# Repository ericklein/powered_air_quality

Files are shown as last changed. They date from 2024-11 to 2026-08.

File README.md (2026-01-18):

# Powered Air Quality
AI: Add hero show with new enclosure :)
## Purpose
Powered Air Quality, aka PAQ, samples, displays, and if connected to WiFi, logs the following air characteristics:
- Temperature (fahrenheit)
- Humidity
- CO2 (carbon dioxide)
- PM2.5 (air particulate)
- VOC (volatile organic compounds) index
- NOx (nitrogen oxide) index (requires SEN6x sensor)

If PAQ is connected to WiFi, it can log this information to a number of network endpoints.

PAQ was created to answer three primary questions:
- Is the co2 level in the room good?
- What is the particulate count in the air outside, and how much of that got into the room? This is particularly relevant during fire season.
- When we use the gas stove or the central heater, how does it change our indoor air quality?

## Associated projects
PAQ has a number of sibling projects that share many common hardware and code attributes. Those are:
- [Air Quality](https://github.com/ericklein/air_quality) has the same functionality as PAQ minus air particulate measurement. It is powered by a battery
- [RCO2](https://github.com/ericklein/rco2) is a small, portable version of Air Quality that only samples and displays air quality levels.
- [Badge](https://github.com/ericklein/badge) is RCO2 in a badge form factor capable of displaying additional information beyond air quality levels.
## Features
NOTE: All screens are engineering art, not final design :)

PAQ exposes air characteristics through a number of screens. When the device is idle, it displays the CO2 ppm level as moving text to protect the screen (eg. screensaver mode)
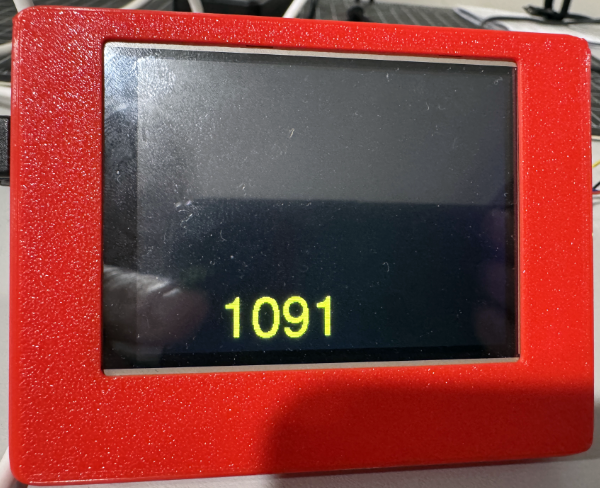
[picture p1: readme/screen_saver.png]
PAQ screensaver picture


If the screen is touched while in screensaver mode, it will display the main menu. Touching any of the options takes the user to the corresponding component information screen.

The main menu varies if the device is configured with a SEN66, which can detect NOx levels
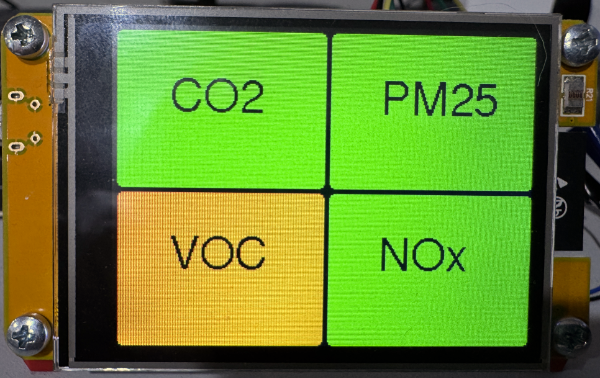
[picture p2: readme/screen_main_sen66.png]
PAQ SEN66 main menu picture


or with the combination of an SCD40 and SEN54, which can not detech NOx levels.
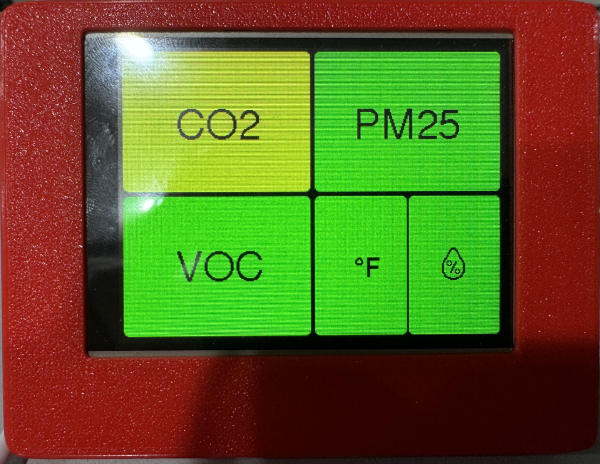
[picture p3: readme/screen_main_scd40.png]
PAQ SCD40 main menu picture


If CO2 is selected from the main menu, it will display a screen highlighting the current CO2 level in ppm and US standard color code level, plus a graph of most recent values. Tapping anywhere on the screen will return to the main menu.
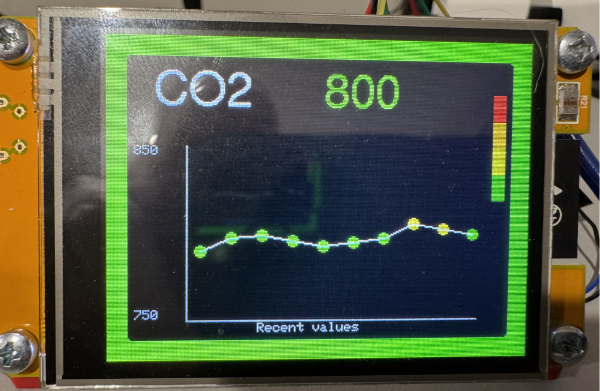
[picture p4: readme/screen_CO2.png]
PAQ co2 screen picture


If VOC is selected from the main menu, it will display a screen highlighting the current VOC level in ppm and US standard color code level, plus a graph of most recent values. Tapping anywhere on the screen will return to the main menu.
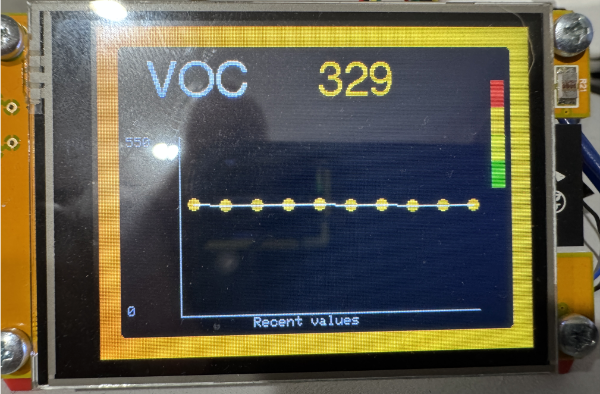
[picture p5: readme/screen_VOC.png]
PAQ VOC screen picture


If PM25 is selected from the main menu, it will display a screen highlighting the current indoor and outdoor PM25 level in ppm and US standard color code level, plus the current outdoor US AQI level. It will also display a red or green database icon if the device is succeeding at logging data to network endpoints. Tapping anywhere on the screen will return to the main menu.
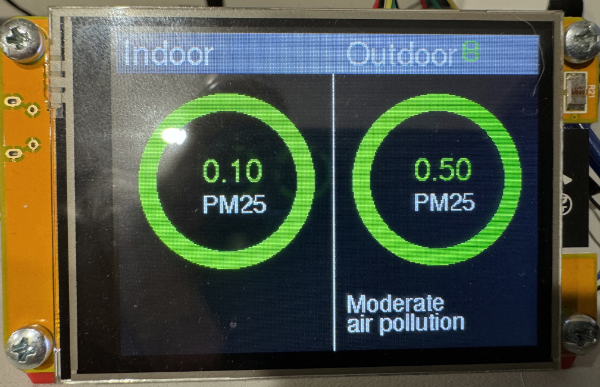
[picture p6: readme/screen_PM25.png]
PAQ PM25 screen picture


If NOx is selected from the main menu, it will display a screen highlighting the current NOx level in ppm and US standard color code level. Tapping anywhere on the screen will return to the main menu.
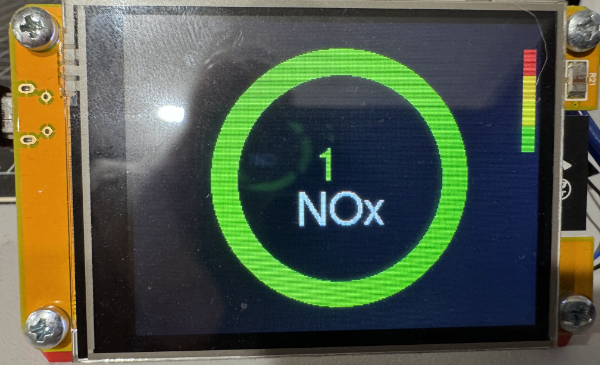
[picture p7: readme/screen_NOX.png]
PAQ SEN66 NOx screen picture


If temp/humidity is selected from the main menu, it will display a screen highlighting the current indoor and outdoor temperature in Fahrenheit and humdidity. It will also display the current WiFi connectivity level in the upper right of the screen. Tapping anywhere on the screen will return to the main menu.
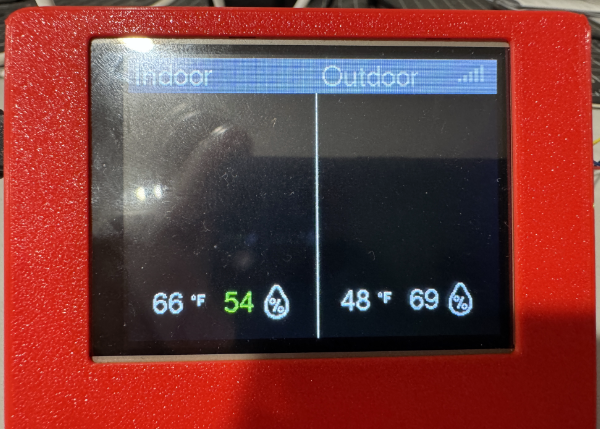
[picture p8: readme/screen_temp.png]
PAQ temp/humidity screen picture

## Target configuration
- Set parameter configuration using config.h
- Private configuration settings including network endpoint credentials are contained in a `secrets.h` file that is not included in this repo.  Instead you'll find the file `secrets_template.h`, which should be copied to `secrets.h` and then edited to supply the right access credentials and configuration values to match your deployment environment.
- Copy the contents of the "put in TFT_eSPI folder" into the "TFT_eSPI" folder found in your Arduino library folder.
- If the device can not connect to a WiFi access point, it will bring up a screen directing you to configure the device via a browser portal window. Entering the configuration data in this portal will then reboot the device and connect to the entered WiFi AP.
## Bill of Materials (BOM)
### MCU
- [CYD (Cheap Yellow Display)])(https://github.com/witnessmenow/ESP32-Cheap-Yellow-Display/tree/main). This is an inexpensive ESP32 prototype board with a built-in screen.
    - Arduino IDE should be told to target the "ESP32 Dev Module" board, which you can find once you install the ESP32 BSP
    - Code is portable to any ESP32 MCU
### WiFi
- [CYD (Cheap Yellow Display)])(https://github.com/witnessmenow/ESP32-Cheap-Yellow-Display/tree/main). This is an inexpensive ESP32 prototype board with a built-in screen.
    - Code is portable to any ESP32 MCU
### Sensors
Two sensor payloads are supported by PAQ
- Option 1
    - [Sensirion SCD40](readme/Sensirion_CO2_Sensors_SCD4x_Datasheet.pdf), measuring temperature, humidity, and CO2
    and
    - [Sensirion SEN54](readme/Sensirion_Datasheet_Environmental_Node_SEN5x.pdf), measuring pm1, pm25, pm4, pm10, humidity, temperature, and VOC index 
- Option 2
    - [Sensirion SEN66](readme/Sensirion_Datasheet_SEN6x.pdf), measuring pm1, pm25, pm4, pm10, humidity, temperature, VOC index, and NOx index

Support for the [Plantower PMSA003I](https://www.adafruit.com/product/4632), which has a subset of the SEN5x functionality, was deprecated by can be found in older code versions.
### Screen
- [CYD (Cheap Yellow Display)])(https://github.com/witnessmenow/ESP32-Cheap-Yellow-Display/tree/main). This is an inexpensive ESP32 prototype board with a built-in screen.
    - any CYD screen using a ILI9341 driver is supported, ST7789 based screens are not supported
### Buttons/Switches
- Touchscreen support is used for user input.
## Pinouts
### SCD40
- Connected through Stemma QT cable to SEN5X adapter board
### SEN54
- Connected to CYD through a custom cable and SEN54 to [Adafruit SEN5x to i2c adapter board](https://www.adafruit.com/product/5964)
#### Custom cable from CYD to SEN5X adapter board
- CYD connector is [JST 1.25mm pitch 4 pin](https://www.amazon.com/dp/B0DFCHWTXK?ref=fed_asin_title&th=1)
- Adafruit connector is JST SH 1.0mm pitch 4 pin
    - I cut the male breadboard ends off this [Adafruit cable](https://www.adafruit.com/product/4209) to get the appropriate second part of the cable
- This custom cable attaches to CYD connector CN1
    - GND to GND
    - GPIO 22 to SDA (often Blue) pin
    - GPIO 27 to SCL (often Yellow) pin
    - 3.3v to 3.3v
## Supported network endpoints
### MQTT
- uncomment #define MQTT in config.h
- set appropriate parameters in config.h and secrets.h
    - Technical References
        - https://hackaday.com/2017/10/31/review-iot-data-logging-services-with-mqtt/
### Hassio MQTT
- AI: ADD DOCUMENTATION
### InfluxDB
- AI: ADD DOCUMENTATION
## Software Dependencies
- ArduinoJson by Benoit Blanchon
- Adafruit ILI9341 (and dependencies)
- Sensirion I2C SEN5X (and dependencies)
- Sensirion I2C SCD4x (and dependencies)
- ESP8266 Influxdb by Tobias Schurg (which also works for ESP32 despite the name)
## Issues and Feature Requests
- [Github Issues](https://github.com/ericklein/powered_air_quality/issues)
## .plan (big ticket items)
- [WiFI Manager](https://github.com/tzapu/WiFiManager) support
- OTA firmware update support
- button support to cycle through multiple information screens
## Supporting Material
### Screen
- https://cdn-learn.adafruit.com/downloads/pdf/adafruit-gfx-graphics-library.pdf
### Temperature and Humdity
- [Ideal indoor humidity](https://iaq.works/humidity/indoor-humidity-level-why-is-the-40-60-range-ideal/)
### CO2 (Carbon Dioxide)
#### Scales
We currently use the following scale, which is modifiable in config.h:
- <800 - Good
- 800-999 - So-So
- 1000+ - Poor
##### Alternate ideas
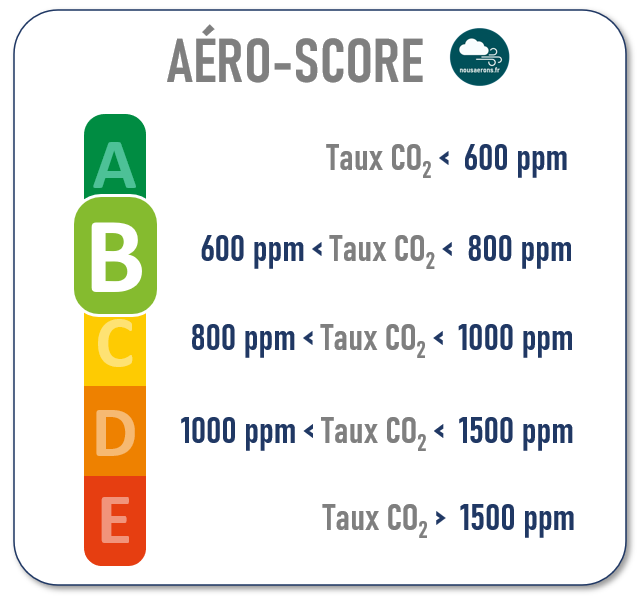
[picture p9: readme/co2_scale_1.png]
Example 1
- 
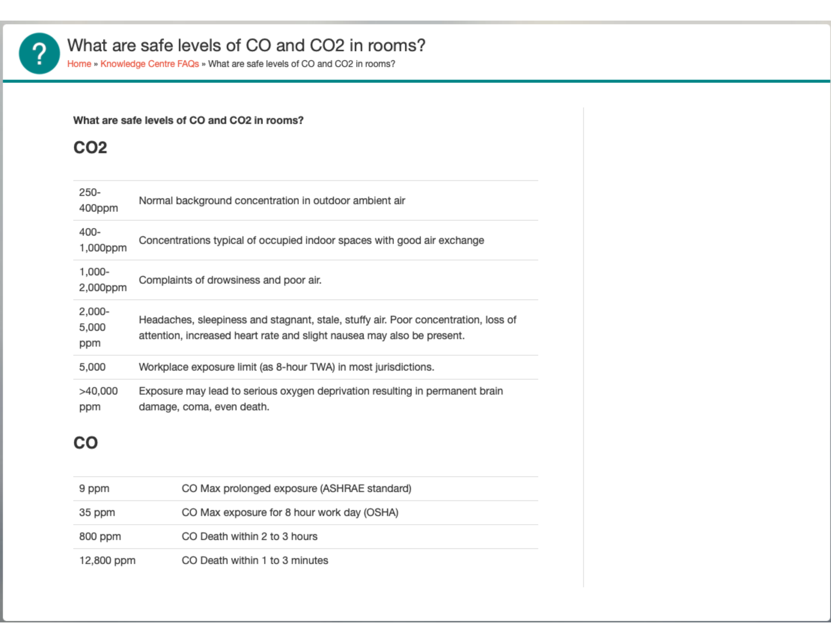
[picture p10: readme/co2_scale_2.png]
Example 2
- 
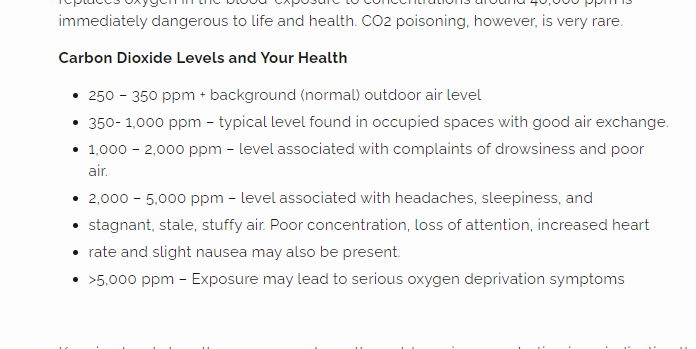
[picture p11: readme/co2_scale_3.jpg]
Example 3
- 
- US NIOSH (1987) recommendations:
    - 250-350 ppm - normal outdoor ambient concentrations
    - 600 ppm - minimal air quality complaints
    - 600-1,000 ppm - less clearly interpreted
    - 1,000 ppm - indicates inadequate ventilation; complaints such as headaches, fatigue, and eye and throat irritation will be more widespread; 1,000 ppm should be used as an upper limit for indoor levels
#### Impact on health
- [CO2 and indoor air quality](readme/CO2_and_indoor_air_quality.pdf)
#### Sensors
- [CO2 sensor types](https://www.airgradient.com/blog/co2-sensors-photo-acoustic-vs-ndir-updated/)
- SCD40 sensor
    - [SCD40 datasheet](readme/Sensirion_CO2_Sensors_SCD4x_Datasheet.pdf)
### AQI
- [AQI Overview](readme/aqi_overview.md)
- https://en.wikipedia.org/wiki/Air_quality_index#CAQI
- [Open Weather Map Air Pollution API](https://openweathermap.org/api/air-pollution)
- [OSHA Air Quality](readme/OSHA_Indoor_Air_Quality.pdf)
- [Great site for air quality info](https://itsairborne.com/)
- [NYT on indoor gas stoves](https://www.nytimes.com/2023/01/29/climate/gas-stove-health.html)
#### Scales
We currently use the following scale, which is modifiable in config.h:

- 0-25 : "Good" : Green
- 26-50 : "Fair" : Yellow
- 51-150 : "Poor" : Orange
- 151+ : "Bad" : Red

Options:
- Open Weather Map scale
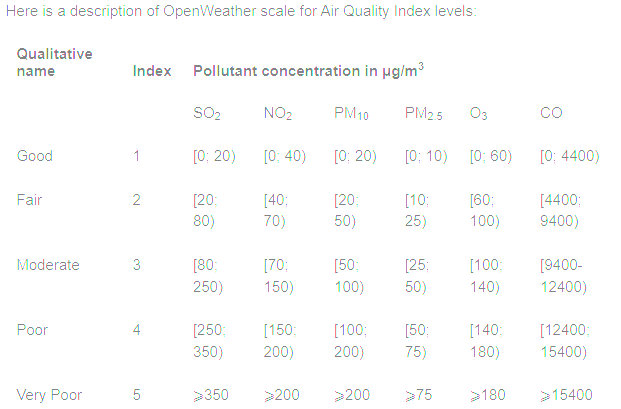
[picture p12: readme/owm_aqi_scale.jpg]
owm scale

- Aware scale
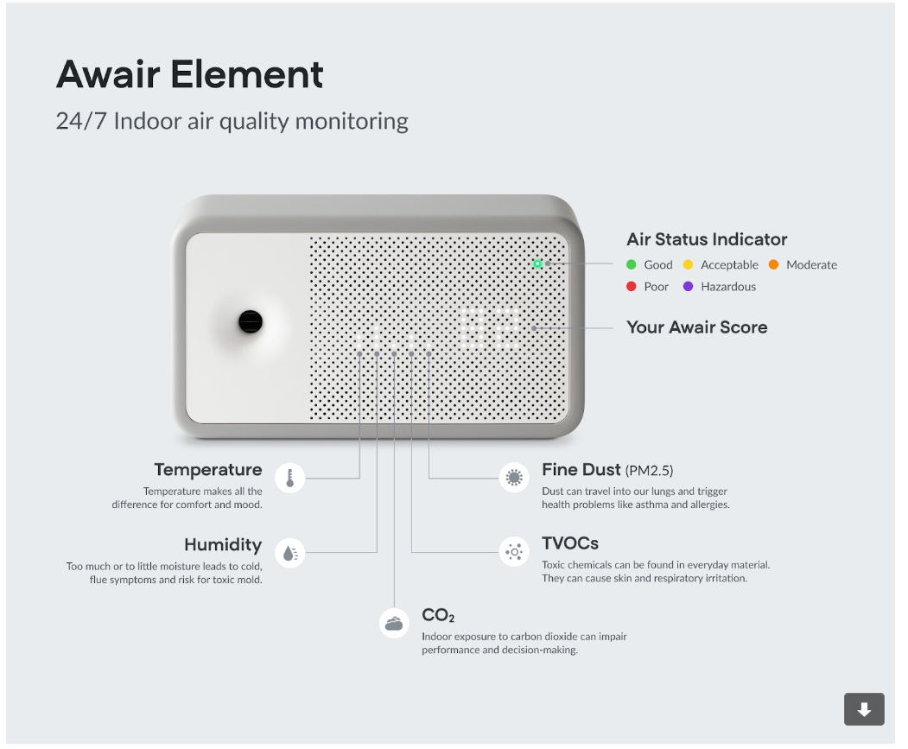
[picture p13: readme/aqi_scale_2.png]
awair scale

- Australian local goverment scale
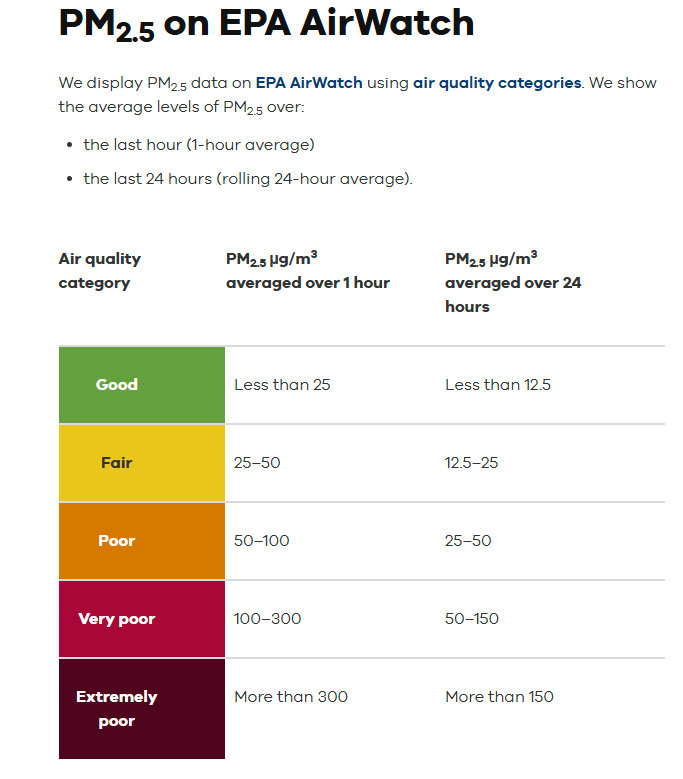
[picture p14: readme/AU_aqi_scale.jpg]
victoria scale

- government standard scale
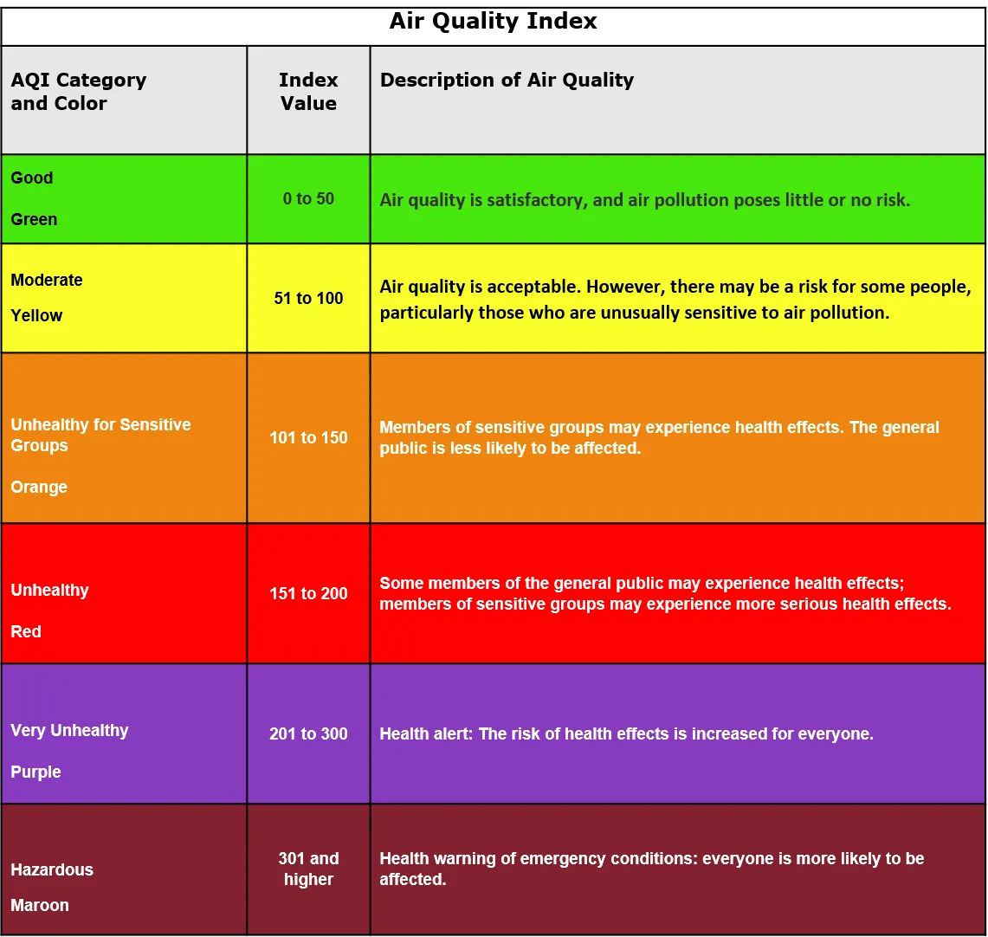
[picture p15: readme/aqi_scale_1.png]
AQI scale

### VOC (Volatile Organic Compounds)
[Sensirion documentation on VOC](readme/Info_Note_VOC_Index.pdf)
#### Scale
We currently use the following scale, which is modifiable in config.h:

- 0-150 : "Good" : Green
- 151-250 : "Fair" : Yellow
- 251-400 : "Poor" : Orange
- 401+ : "Bad" : Red

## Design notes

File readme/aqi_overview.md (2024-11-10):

# Air Quality Index (AQI) overview
It's worth noting that while most people have heard of an "Air Quality Index" from their local weather service or news, the calculation of AQI from sensor readings is less well known.  Sensors measure and report particulate concentrations in various size ranges, the most widely used of which is "PM2.5", meaning airborne particulates of 2.5 microns in diameter or smaller, measured in micrograms per cubic meter.  
The more particulates measured the worse the air quality and, eventually, the greater the danger to humans and animals.  Howeveer, the perceived quality of the air and the risk from exposure vary in a non-obvious way based on the actual PM2.5 values observed.
That variability is what gave rise to the idea of an Air Quality Index in the first place, though as is often the case in associating health factors and risk with environmental data different governing bodies and standards organizations have put forward different ways of calculating risk from sensor data.  You can read much more about this in the Wikipedia page for [Air Quality](https://en.wikipedia.org/wiki/Air_quality_index).
In the US, the Environmental Protection Agency (EPA) developed its own AQI measure, dividing the normal range of measured particulates and pollutants into six categories indicating increased levels of health concerns.  An overall AQI value is calculated from a piecewise linear function, with scaling and transition points defined by the EPA.  More details on that math are shared in the Wikipedia page cited above, as well as this [post](https://forum.airnowtech.org/t/the-aqi-equation/169) on the AirNow tech forum.

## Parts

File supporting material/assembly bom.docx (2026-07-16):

# Climatron BOM

□ CYD JC2432W328

□ flashed □ LED removed

□ chassis

□ SEN66

□ SEN 66 i2c board

□ JST 1.25 to i2c 4pin cable

□ SEN66 GH 6pin cable (i2c to SEN66)

□ LED strip (JST PH 2.0 socket) [1]

□ speaker

□ USB power cable [2]

Connected to 3,4

□ 5v power cable [3]

Connected to 2,6

□ JST 1.25 power connection [4]

Connected to CYD, 2

□ JST 1.25 LED/gnd cable [5]

Connected to CYD, 6

□ JST PH 2.0 male merge [6]

Connected to 3,5; socketed to 1

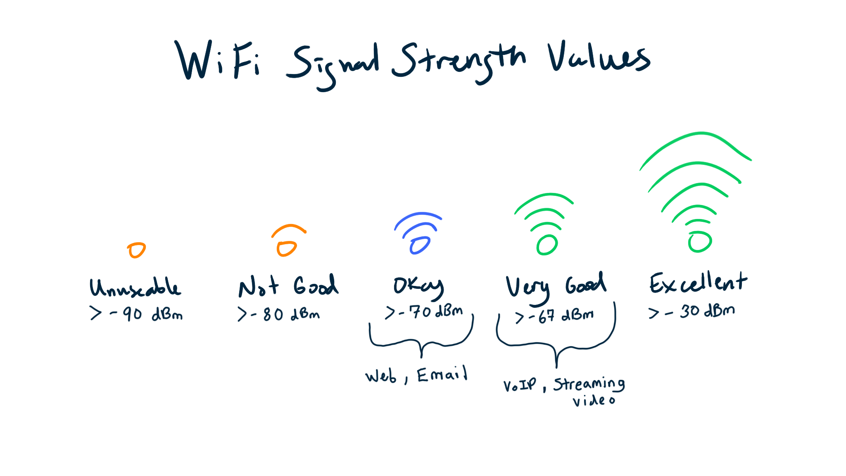
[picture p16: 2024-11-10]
supporting material/WiFi Signal Strength values.webp

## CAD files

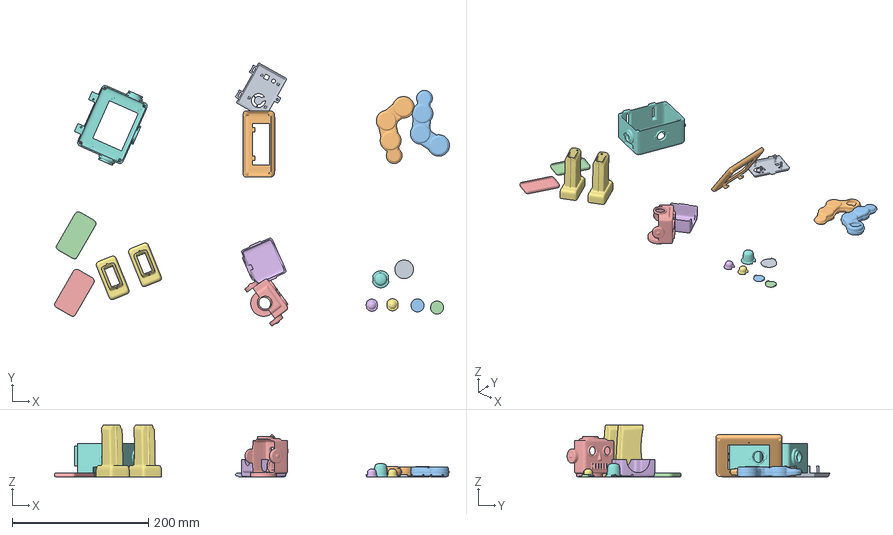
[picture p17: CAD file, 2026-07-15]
supporting material/case/complete_4_26_2026_rev.3mf
580.3 x 386.0 x 75.7 mm
door_9.stl
ARM_LEFT.stl
ARM_RIGHT.stl
footbase.stl x 2
EYE_MAIN2.stl x 2
KLAXON.stl
KLAXON_BAK.stl
chest_bak.stl
EYE_BAK2.stl x 2
head_main
head_baCK.stl
legs.stl
torst_6.stl

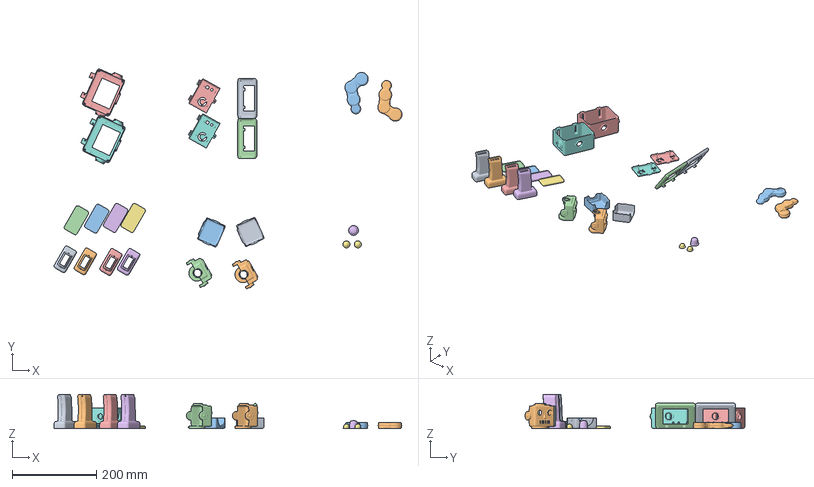
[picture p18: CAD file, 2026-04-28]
supporting material/case/complete_2_20_2026.3mf
827.4 x 522.9 x 81.1 mm
back_9.stl x 2
ARM_RIGHT.stl
ARM_LEFT.stl
door_9.stl x 2
footbase.stl x 4
leg_r.stl x 2
leg_l.stl x 2
HEAD_BACK5stl.stl x 2
head_front_6.stl x 2
torso_7.stl x 2
klaxon2.stl
eyes2.stl

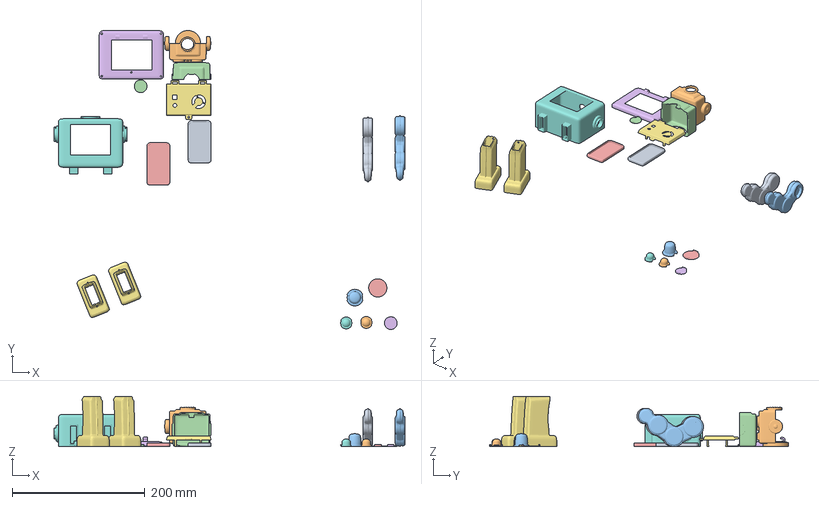
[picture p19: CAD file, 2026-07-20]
supporting material/case/case 042626.3mf
528.0 x 449.8 x 75.7 mm
ARM_LEFT.stl
head_main
ARM_RIGHT.stl
head_baCK.stl
footbase.stl x 2
chest_bak.stl
door_9.stl
EYE_MAIN2.stl x 2
KLAXON.stl
EYE_BAK2.stl x 2
KLAXON_BAK.stl
legs.stl
torst_6.stl

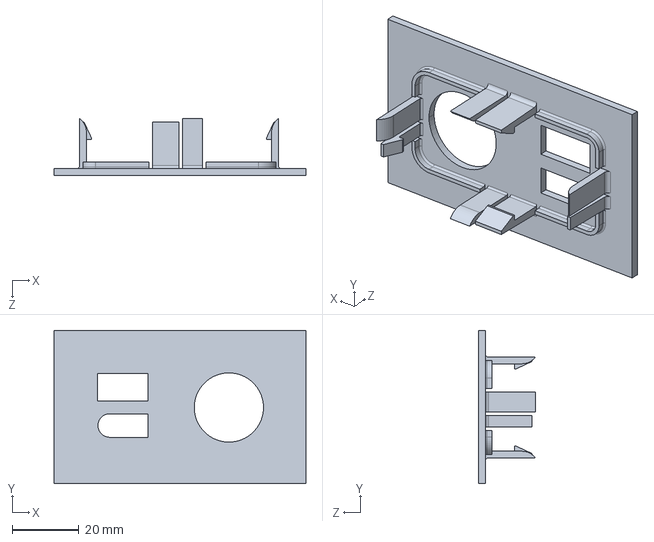
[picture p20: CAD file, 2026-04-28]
supporting material/case/sen66 retainer for mockups.STEP
75.5 x 45.9 x 17.0 mm

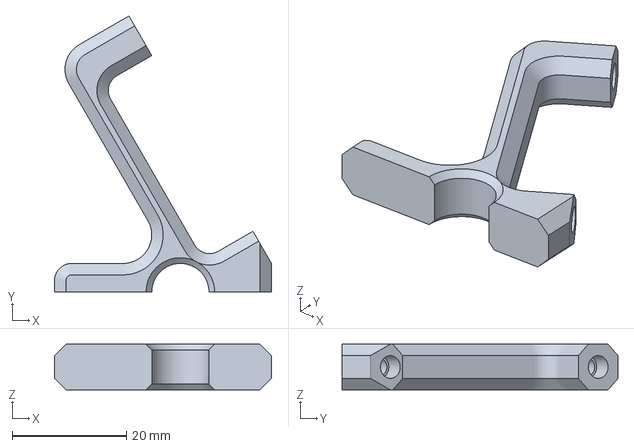
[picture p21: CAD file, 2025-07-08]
supporting material/case/CYD Stand Leg Landscape.3mf
38.0 x 48.3 x 8.00 mm

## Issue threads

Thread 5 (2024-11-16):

A few suggested enhancements to help in getting started

disquisitioner, 2024-11-16:
As a way of getting familiar with PAQ and the CYD I attempted to start from scratch with a new dev board, no sensors, and an empty repo based just on cloning main.  My two part goal was to (1) get everything to compile and (2) to then get the program running in hardware simulation mode.  I was successful, but in the process found a few things that could enhance the documentation (README) and bits of the code:

1.  I think it'd be good to list in the README the library dependencies, which I discovered to be:
      *) ArduinoJson by Benoit Blanchon
      *) Adafruit ILI9341 (and dependencies)
      *) Sensirion I2C SEN5X (and dependencies)
      *) Sensirion I2C SCD4x (and dependencies)
      *) ESP8266 Influxdb by Tobias Schurg (which also works for ESP32 despite the name)

2. For the CYD the Arduino IDE should be told to target the "ESP32 Dev Module" board, which you can find once you install the ESP32 BCP

3.  The code presumes a few Open Weather Map configuration parameters are defined, presumably in `secrets.h`, but they're not included in `secrets_template.h`.  I'd suggest adding place holder examples for these in `secrets_template.h`:
      *) `OWM_LAT_LONG` (which needs to be in a special format, e.g. `"lat=44.34&lon=10.99"`)
      *) `OWM_KEY` (which people need to obtain by creating an account at https://openweathermap.org/)

4. By default InfluxDB services are enabled in `config.h` but probably shouldn't be to parallel the approach used for MQTT. This could be mentioned in the README as is the case now for MQTT.

I could submit a PR for these but would want to coordinate with work underway in the `dev `branch,  Perhaps I could do that after the work in the dev branch gets merged into main.

With the above, enabling HARDWARE_SIMULATE in config.h worked the first time, yielding a working instance of PAQ with no sensors attached but with reasonable simulated values.  NICE!!

ericklein, 2024-11-17:
Suggested documentation changes and secret_template.h changes rolled into /dev and will be promoted to /main shortly.

Closed 2024-11-17.

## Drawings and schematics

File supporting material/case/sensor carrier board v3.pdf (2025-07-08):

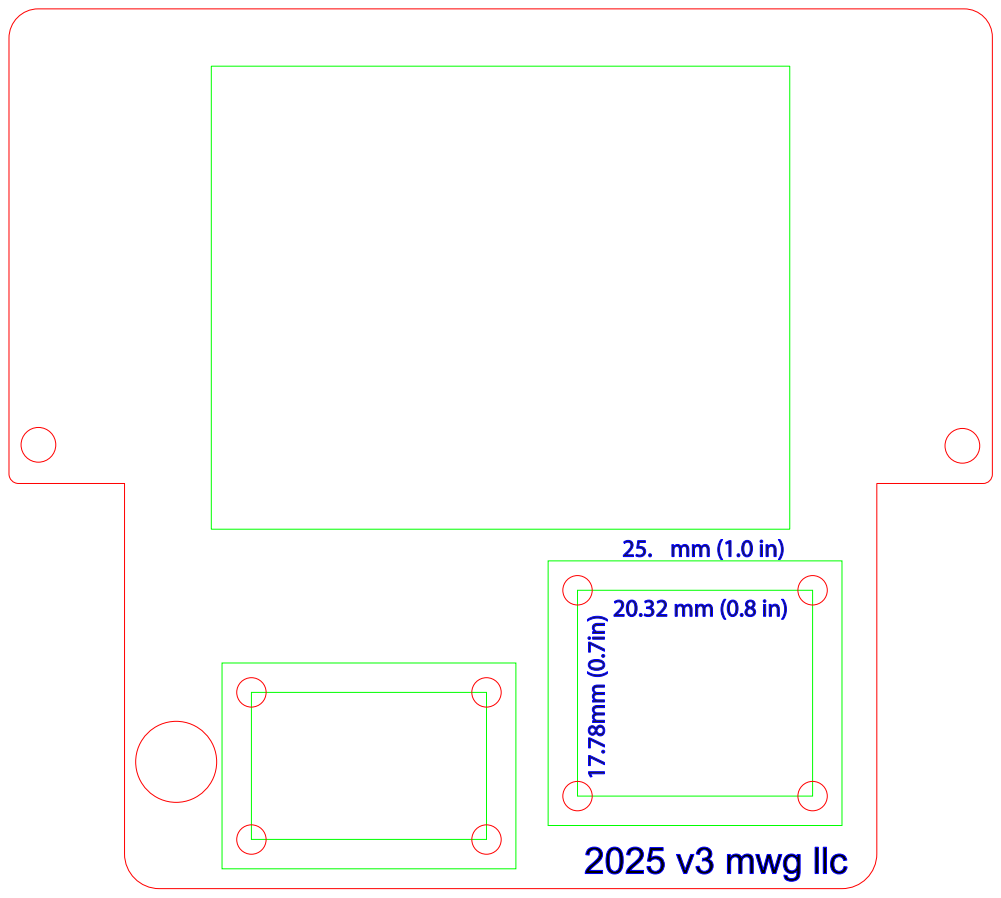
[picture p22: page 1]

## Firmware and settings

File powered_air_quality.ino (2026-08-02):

/*
  Project:        Powered Air Quality
  Description:    Sample and log indoor air quality

  See README.md for target information
*/

#include "config.h"               // hardware and internet configuration parameters
#include "powered_air_quality.h"  // global data structures
#include "secrets.h"              // private credentials for network, MQTT
#include "data.h"

// #include <math.h>
#include <HTTPClient.h>           // used to access Open Weather Map
#include <WiFiManager.h>          // https://github.com/tzapu/WiFiManager
#include <Measure.hpp>            // https://github.com/disquisitioner/Measure, utility class for collecting, processing, and reporting periodic data
#include <Preferences.h>          // read-write to ESP32 persistent storage
#include <TimeLib.h>              // https://github.com/PaulStoffregen/Time, used to process OWM Forecast
#include <TFT_eSPI.h>             // https://github.com/Bodmer/TFT_eSPI
#include <XPT2046_Touchscreen.h>  // https://github.com/PaulStoffregen/XPT2046_Touchscreen
#include <ArduinoJson.h>          // https://github.com/bblanchon/ArduinoJson, used by OWM retrieval routines

#include "ui/fonts/Roboto_Regular_18.h"
#include "ui/fonts/Roboto_Regular_24.h"
#include "ui/fonts/Roboto_Regular_36.h"

// instanstiate SEN5X hardware object
#include <SensirionI2CSen5x.h>
SensirionI2CSen5x pmSensor;

// instanstiate SCD4X hardware object
#include <SensirionI2cScd4x.h>
SensirionI2cScd4x co2Sensor;

Preferences nvConfig;

// WiFiManager global configuration
WiFiClient client;   // WiFiManager loads WiFi.h, which is used by OWM and MQTT
WiFiManager wfm;

// WiFiManager parameter backing buffers
char wfmLatitudeStr[20];
char wfmLongitudeStr[20];
char wfmAltitudeStr[6];
char wfmMqttPortStr[6];
char wfmInfluxPortStr[6];

// Persistent WiFiManagerParameter pointers
WiFiManagerParameter* pHintText = nullptr;
WiFiManagerParameter* pSeparator = nullptr;

WiFiManagerParameter* pDeviceLatitude = nullptr;
WiFiManagerParameter* pDeviceLongitude = nullptr;
WiFiManagerParameter* pDeviceAltitude = nullptr;
WiFiManagerParameter* pDeviceID = nullptr;

#if defined(MQTT) || defined(INFLUX) || defined(HASSIO_MQTT)
  WiFiManagerParameter* pDeviceSite = nullptr;
  WiFiManagerParameter* pDeviceLocation = nullptr;
  WiFiManagerParameter* pDeviceRoom = nullptr;
#endif

#ifdef MQTT
  WiFiManagerParameter* pMQTTHeader = nullptr;
  WiFiManagerParameter* pMqttBroker = nullptr;
  WiFiManagerParameter* pMqttPort = nullptr;
  WiFiManagerParameter* pMqttUser = nullptr;
  WiFiManagerParameter* pMqttPassword = nullptr;
#endif

#ifdef INFLUX
  WiFiManagerParameter* pInfluxHeader = nullptr;
  WiFiManagerParameter* pInfluxBroker = nullptr;
  WiFiManagerParameter* pInfluxPort = nullptr;
  WiFiManagerParameter* pInfluxOrg = nullptr;
  WiFiManagerParameter* pInfluxBucket = nullptr;
  WiFiManagerParameter* pInfluxEnvMeasurement = nullptr;
  WiFiManagerParameter* pInfluxDevMeasurement = nullptr;
#endif

bool wfmParametersAdded = false;
bool wfmPortalRunning = false;
bool saveWFMConfig = false;
uint32_t wfmPortalStartMS = 0;

// 2.8″ 320x240 color TFT
TFT_eSPI display = TFT_eSPI();
enum screenNames screenCurrent = sMain; // Initial screen to display (on startup)

// Screen specific functions that reside separately in screens.cpp
extern void screenMain();
extern void screenVOC();
extern void screenCO2();
extern void screenPM25();
extern void screenForecast();
// other functions residing in screens.cpp
extern uint8_t co2Range(float);
extern uint8_t pm25Range(float);
extern uint8_t vocRange(float);

// CYD 2432S028R -> XPT2046
SPIClass touchscreenSPI = SPIClass(VSPI);
XPT2046_Touchscreen touchscreen(pinTouchCS,pinTouchIRQ);

#ifdef THINGSPEAK
  extern bool post_thingspeak(float pm25, float co2, float temperatureF, float humidity, 
    float vocIndex, float aqi);
#endif

#ifdef INFLUX
  extern bool post_influx(float temperatureF, float humidity, uint16_t co2, float pm25, float vocIndex, uint8_t rssi);
#endif

#ifdef MQTT
  #include <PubSubClient.h>     // https://github.com/knolleary/pubsubclient
  PubSubClient mqtt(client);

  extern bool mqttConnect();
  extern void mqttPublish(const char* topic, const String& payload);
  extern const char* generateMQTTTopic(String key);
  extern bool mqttPublishValue(String key, const String& payload);

  #ifdef HASSIO_MQTT
    extern bool hassio_mqtt_publish(float pm25, float co2, float temperatureF, float humidity, float aqi);
  #endif
#endif

// data structures defined in powered_air_quality.h
networkEndpointConfig endpointPath;
hdweData hardwareData;
OpenWeatherMapAirQuality owmAirQuality;
SiteForecast owmSiteForecast;
influxConfig influxdbConfig; // available globally for nvconfig use
MqttConfig mqttBrokerConfig; // available globally for nvconfig use

// Utility class used to streamline accumulating sensor values, averages, min/max &c.  Each
// instance contains storage to retain points for subsequent processing, which are used
// here to graph recent data. The size of that retatined data is based on the
// kSampleCapacity value defined in config.h.
Measure<kSampleCapacity> totalTemperatureF, totalHumidity, totalCO2, totalVOCIndex, totalPM25;

uint32_t timeLastReportMS = 0;  // timestamp for last report to network endpoints

// alert management
uint32_t alertStartMS = 0;
uint32_t alertLengthMS = 0;
bool alertScreen = false;
bool alertSound = false;

void setup() {
  // config Serial first for debugMessage()
  #ifdef DEBUG
    Serial.begin(115200);
    // wait for serial port connection
    while (!Serial);
    // Display key configuration parameters
    debugMessage(String("Starting Powered Air Quality with ") + (timeSensorSampleMS/1000) + String(" second sample interval"),1);
    #if defined(MQTT) || defined(INFLUX) || defined(HASSIO_MQTT) || defined(THINGSPEAK)
      debugMessage(String("Report interval is ") + (timeReportMS/60000) + " minutes",1);
    #endif
  #endif

  // generate truely random numbers
  randomSeed(esp_random());

  display.begin();
  display.setRotation(screenRotation);
  display.setTextWrap(false);
  display.fillScreen(TFT_BLACK);
  // set LED backlight
  ledcAttach(TFT_BL, 5000, 8); // 5000 = pwm frequency, 8 = bit resolution
  ledcWrite(TFT_BL, screenBLMax);

  display.loadFont(Roboto_Regular_36);
  screenHelperAlert("Initializing",TFT_WHITE,TFT_BLACK,TFT_BLUE);
  display.unloadFont();

  // CYD 2432S028R -> XPT2046
  Wire.begin(pinSensorSDA, pinSensorSCL);
  touchscreenSPI.begin(pinTouchCLK, pinTouchMISO, pinTouchMOSI, pinTouchCS); // setup the VSPI to use CYD touchscreen pins
  touchscreen.begin(touchscreenSPI);
  touchscreen.setRotation(screenRotation);

  // initialize GPIO
  pinMode(pinButton, INPUT_PULLUP);

  ledcAttach(pinAudio, audioFrequency, audioResolution);

  // get configuration data before calling sensorInit() to load altitude value
  if(!nvconfigRead()) {
    // no configuration parameters in non-volatile storage, so write defaults
    nvconfigDefaultsLoad();
    nvconfigWrite();
  }   

  // initialize sensor(s)
  if( !sensorInit()) {
    // error often occurs after firmware flash/reset
    display.loadFont(Roboto_Regular_24);
    deviceReboot("Sensor failure, rebooting", 5000);
    display.unloadFont();
  }
  networkWiFiManagerOpen();
}

void loop() {
  static uint8_t numSamples               = 0;  // Number of sensor readings over reporting interval
  static uint32_t timeLastSampleMS        = -(timeSensorSampleMS); // forces immediate sample in loop() 
  static uint32_t timeLastInputMS         = millis();  // timestamp for last user input (screensaver)
  uint16_t calibratedX, calibratedY;

  // order of operation
  // 0 - update current alerts
  // 1 - feed cycles to web portal
  // 2 - handle touchscreen input
  // 3 - handle button press
  // 4 - read sensor
  // 5 - update screen saver
  // 6 - network endpoint(s) write?

  // update current alerts
  alertHandle();

  // feed processor cycles to the web portal if needed
  if (wfm.getWebPortalActive()) {
    wfm.process();

    if (saveWFMConfig) {
      networkWiFiManagerSaveParameterValues();
      saveWFMConfig = false;
      networkWiFiManagerRefreshParameterValues();
    }

    if (wfmPortalRunning &&
        millis() - wfmPortalStartMS > timeWebPortalTimeOutMS) {
      wfm.stopWebPortal();
      wfmPortalRunning = false;
    }
  }

  // is there user input to process?
  bool touchEvent = false;
  // CYD 2432S028R -> XPT2046
  if (touchscreen.tirqTouched() && touchscreen.touched()) {
    // get raw 12bit touchscreen x,y and then calibrate to screen size
    TS_Point p = touchscreen.getPoint();
    calibratedX = map(p.x, touchscreenMinX, touchscreenMaxX, 1, display.width());
    calibratedY = map(p.y, touchscreenMinY, touchscreenMaxY, 1, display.height());
    // alternate conversion
    // uint16_t calibratedX = (uint16_t)((p.x - touchscreenMinX) * display.width() / (touchscreenMaxX - touchscreenMinX));
    // uint16_t calibratedY = (uint16_t)((p.y - touchscreenMinY) * display.height() / (touchscreenMaxY - touchscreenMinY));
    touchEvent = true;
  }
  if (touchEvent) {
    debugMessage(String("touch input x=") + calibratedX + ", y=" + calibratedY,2);
    ledcWrite(TFT_BL, screenBLMax);
    if (screenCurrent == sMain) {
      if (calibratedY < 122) { // top components
        if (calibratedX < 107) {
          screenCurrent = sForecast;
        }
        else {
          screenCurrent = sCO2;
        }
      }
      else {
        if (calibratedX < 107) {
          screenCurrent = sVOC;
        }
        else {
            // only PM25 guage displayed
            if (calibratedX < 214) {
              screenCurrent = sPM25;
            }
        }
      }
    }
    else {
      screenCurrent = sMain;
    }
    screenUpdate(screenCurrent);
    timeLastInputMS = millis();
  }

  // (reset) button press that needs to be handled?
  checkButtonPress();

    // is it time to read the sensor?
  if ((millis() - timeLastSampleMS) >= timeSensorSampleMS) {
    // Read sensor(s)
    if (sensorRead()) {
      numSamples++;
      // IMPROVEMENT: evaluate whether the screen actually needs updated based on changed data
      screenUpdate(screenCurrent);
      if (sampleEvaluate()) {
        // ALERT: 5 second, sound, LED, and screen
        alertLengthMS = 5000;
        alertStartMS = millis();
        alertScreen = true;
        alertSound = true;
        ledcWriteTone(pinAudio, audioFrequency);
        display.loadFont(Roboto_Regular_24);
        screenHelperAlert("CO2 rising rapidly", TFT_WHITE,TFT_BLACK,TFT_RED);
        display.unloadFont();
      }
    }
    else {
      // ALERT: 5 second screen alert, no sound or LEDs
      alertScreen = true;
      alertLengthMS = 5000;
      alertStartMS = millis();
      display.loadFont(Roboto_Regular_24);
      screenHelperAlert("Sensor read fail", TFT_WHITE,TFT_BLACK,TFT_YELLOW);
      display.unloadFont();
    }
    // Save last sample time
    timeLastSampleMS = millis();
  }

  // is it time to enable the screensaver?
  if ((millis() - timeLastInputMS) > timeScreenSaverStartMS) {
    ledcWrite(TFT_BL, screenBLLow);
  }

  // is it time to write to the network endpoints?
  if ((millis() - timeLastReportMS) >= timeReportMS) {
    samplePost(numSamples);
    timeLastReportMS = millis();
  }
}

void screenUpdate(uint8_t screenCurrent) 
{
  switch(screenCurrent) {
    case sMain:
      screenMain();
      break;
    case sVOC:
      screenVOC();
      break;
    case sCO2:
      screenCO2();
      break;
    case sPM25:
      screenPM25();
      break;
    case sForecast:
      screenForecast();
      break;
  }
}

/**
 * @brief Draw a centered rounded-rectangle "bubble" containing a one- or two-line message.
 *
 * The message is split using pixel width measurements and word boundaries. If the message
 * is too long, truncation is applied at the end of the overall message (ellipsis on line 2
 * only, or on line 1 if it must be single-line). The rounded rectangle and text are constrained
 * to stay within the display and within a horizontal safe region defined by @p kXMargins.
 *
 * Vertical centering behavior:
 * - If two lines are drawn, the vertical gap between the lines is centered on the screen.
 * - If one line is drawn, the text itself is centered on the screen.
 *
 * @param messageText Message to render inside the bubble.
 * @param fgColor   Text color.
 * @param bgColor   Bubble fill color (also used as text background color).
 * @param borderColor Bubble outline color.
 * @param kXMargins    Horizontal safe margin in pixels applied to both left and right edges.
 *
 * @note Set the desired font and text size on @p display before calling this function.
 */
void screenHelperAlert( const String &messageText, uint16_t fgColor, uint16_t bgColor, uint16_t borderColor) {
  debugMessage(String("screenHelperAlert start()"),1);

  display.setTextColor(fgColor, bgColor, true);
  display.setTextPadding(0);

  const int16_t screenW = (int16_t)display.width();
  const int16_t screenH = (int16_t)display.height();
  const int16_t centerY = screenH / 2;

  const int16_t safeLeft  = (int16_t)kXMargins;
  const int16_t safeRight = (int16_t)(screenW - 1 - (int16_t)kXMargins);
  const int16_t safeW     = safeRight - safeLeft + 1;
  if (safeW <= 0) return;

  const uint16_t lineHeight = (uint16_t)display.fontHeight();

  uint8_t lineSpacing = (uint8_t)(lineHeight / 4);
  if (lineSpacing < 2)  lineSpacing = 2;
  if (lineSpacing > 10) lineSpacing = 10;

  uint8_t padX = (uint8_t)(lineHeight / 3);
  uint8_t padY = (uint8_t)(lineHeight / 4);
  if (padX < 6) padX = 6;
  if (padY < 4) padY = 4;

  uint8_t radius = (uint8_t)(lineHeight / 3);
  if (radius < 6)  radius = 6;
  if (radius > 18) radius = 18;

  const int16_t innerW_signed = safeW - (int16_t)(2 * padX);
  const uint16_t innerW = (innerW_signed > 0) ? (uint16_t)innerW_signed : 0;
  if (innerW == 0) return;

  String line1, line2;
  textSplitTwoLines(messageText, line1, line2, innerW);

  const bool twoLines = (line2.length() > 0);

  const int16_t w1 = (int16_t)display.textWidth(line1);
  const int16_t w2 = twoLines ? (int16_t)display.textWidth(line2) : 0;
  const int16_t textW = (w2 > w1) ? w2 : w1;

  const int16_t textH = twoLines
    ? (int16_t)(2 * (int16_t)lineHeight + (int16_t)lineSpacing)
    : (int16_t)lineHeight;

  int16_t rectW = textW + (int16_t)padX * 2;
  int16_t rectH = textH + (int16_t)padY * 2;

  if (rectW > safeW)   rectW = safeW;
  if (rectH > screenH) rectH = screenH;

  int16_t yTextTop;
  if (!twoLines) {
    yTextTop = centerY - (textH / 2);
  } else {
    const int16_t halfGapTop = (int16_t)(lineSpacing / 2);
    yTextTop = centerY - halfGapTop - (int16_t)lineHeight;
  }

  int16_t rectX = safeLeft + (safeW - rectW) / 2;
  int16_t rectY = yTextTop - (int16_t)padY;

  const int16_t maxRectX = safeLeft + safeW - rectW;
  if (rectX < safeLeft) rectX = safeLeft;
  if (rectX > maxRectX) rectX = maxRectX;

  if (rectY < 0) rectY = 0;
  if (rectY + rectH > screenH) rectY = screenH - rectH;

  const int16_t rectCenterX = rectX + rectW / 2;

  display.fillRoundRect(rectX, rectY, rectW, rectH, radius, bgColor);
  display.drawRoundRect(rectX, rectY, rectW, rectH, radius, borderColor);

  display.setTextDatum(TC_DATUM);
  const int16_t textTopY = rectY + (int16_t)padY;

  display.drawString(line1, rectCenterX, textTopY);
  if (twoLines) {
    display.drawString(line2, rectCenterX,
                   textTopY + (int16_t)lineHeight + (int16_t)lineSpacing);
  }

  debugMessage(String("screenHelperAlert end()"), 1);
}

bool sampleEvaluate()
{
  debugMessage(String("sampleEvaluate() start"), 1);

  static bool trendAlreadyReported = false;

  const uint16_t stored = totalCO2.getStored();

  if (stored < (kRequiredRisingDeltas + 1))
  {
    trendAlreadyReported = false;
    return false;
  }

  const uint16_t startIndex = stored - (kRequiredRisingDeltas + 1);

  float deltas[kRequiredRisingDeltas];

  for (uint8_t i = 0; i < kRequiredRisingDeltas; ++i)
  {
    const uint16_t sampleIndex = startIndex + i;

    deltas[i] = totalCO2.getMember(sampleIndex + 1)
              - totalCO2.getMember(sampleIndex);
  }

  float meanDelta = 0.0f;
  for (uint8_t i = 0; i < kRequiredRisingDeltas; ++i)
  {
    meanDelta += deltas[i];
  }
  meanDelta /= kRequiredRisingDeltas;

  float variance = 0.0f;
  for (uint8_t i = 0; i < kRequiredRisingDeltas; ++i)
  {
    const float diff = deltas[i] - meanDelta;
    variance += diff * diff;
  }
  variance /= kRequiredRisingDeltas;

  const float stdDelta = sqrtf(variance);
  const float threshold = fmaxf(kSigmaMultiplier * stdDelta, kMinSigmaFloor);

  bool rapidRisingTrend = true;

  for (uint8_t i = 0; i < kRequiredRisingDeltas; ++i)
  {
    if (deltas[i] < threshold)
    {
      rapidRisingTrend = false;
      break;
    }
  }

  if (rapidRisingTrend && !trendAlreadyReported)
  {
    trendAlreadyReported = true;

    debugMessage(
      String("Rapid CO2 rise detected across last ")
      + (kRequiredRisingDeltas + 1)
      + " samples",
      1
    );

    return true;
  }

  if (!rapidRisingTrend)
  {
    trendAlreadyReported = false;
  }

  debugMessage(String("sampleEvaluate(): no sustained trend detected"), 2);
  debugMessage(String("sampleEvaluate() end"),1);
  return false;
}

/**
 * @brief Process and report accumulated sensor samples.
 *
 * Computes averaged sensor values from accumulated sample buffers and reports
 * them to enabled network endpoints (ThingSpeak, InfluxDB, MQTT, Home Assistant),
 * depending on compile-time configuration and network availability.
 *
 * If no samples are available, the function exits without performing any
 * reporting.
 *
 * After processing, all accumulated sample buffers are cleared and the
 * sample counter is reset to zero to prepare for the next sampling interval.
 *
 * @param[in,out] numSamples Reference to the number of samples accumulated
 *                           during the current reporting interval. A value
 *                           greater than zero indicates that samples are
 *                           available for processing. This value is reset
 *                           to zero after processing.
 *
 * @note Network reporting is skipped if WiFi is not connected.
 * @note Endpoint support is controlled via compile-time flags
 *       (THINGSPEAK, INFLUX, MQTT, HASSIO_MQTT).
 * @note The sample counter is reset regardless of whether reporting succeeds.
 */
void samplePost(uint8_t& numSamples)
{
  debugMessage(String("samplePost() start"),1);

  // do we have samples to process?
  if (numSamples) {
    // can we report to network endPoints?
    #ifndef HARDWARE_SIMULATE
      // attemot to reconnect to WiFi if needed
      if (WiFi.status() != WL_CONNECTED) {
        WiFi.reconnect();
      }

      if (WiFi.status() == WL_CONNECTED) {
        // Get averaged sample values from Measure class objects for endPoint reporting
        float avgTemperatureF = totalTemperatureF.getAverage();
        float avgHumidity = totalHumidity.getAverage();
        uint16_t avgCO2 = totalCO2.getAverage();
        float avgVOC = totalVOCIndex.getAverage();
        float avgPM25 = totalPM25.getAverage();
        float aqi = pm25toAQI_US(avgPM25);

        debugMessage(String("Averages being sent to endpoints for the last ") + (timeReportMS/60000) + " minutes",2);
        debugMessage(String("PM2.5: ") + avgPM25 + "ppm, CO2: " + avgCO2 + "ppm, " + avgTemperatureF + "F, humidity: " + avgHumidity + "%", 2);

        // update RSSI before publishing
        hardwareData.rssi = networkRSSIRead();

        #ifdef THINGSPEAK
          if (!post_thingspeak(avgPM25, avgCO2, avgTemperatureF, avgHumidity, avgVOC, pm25toAQI_US(avgPM25)) ) {
            debugMessage(String("ERROR: Did not write to ThingSpeak"),1);
          }
        #endif

        #ifdef INFLUX
          if (!post_influx(avgTemperatureF, avgHumidity, avgCO2 , avgPM25, avgVOC, hardwareData.rssi))
            debugMessage(String("ERROR: Did not write to InfluxDB"),1);
        #endif

        #ifdef MQTT
          if(mqttConnect()) {
            // publish device data
            const char* topic;

            // publish hardware data
            mqttPublishValue(VALUE_KEY_RSSI, String(hardwareData.rssi));

            // publish sensor data
            mqttPublishValue(VALUE_KEY_TEMPERATURE, String(avgTemperatureF));
            mqttPublishValue(VALUE_KEY_HUMIDITY, String(avgHumidity));
            mqttPublishValue(VALUE_KEY_PM25, String(avgPM25));
            mqttPublishValue(VALUE_KEY_VOC, String(avgVOC));
            mqttPublishValue(VALUE_KEY_CO2, String(avgCO2));

            #ifdef HASSIO_MQTT
              debugMessage("Establishing MQTT for Home Assistant",1);
              // Either configure sensors in Home Assistant's configuration.yaml file
              // directly or attempt to do it via MQTT auto-discovery
              // hassio_mqtt_setup();  // Config for MQTT auto-discovery
              hassio_mqtt_publish(avgPM25, avgCO2, avgTemperatureF, avgHumidity, avgVOC, aqi);
            #endif

            mqtt.disconnect();
          }
        #endif
      }
      else {
        debugMessage("No network, endpoint reporting skipped",1);
      }
    #endif
  }      
  else {
    // ALERT: 5 second, sound, LED, and screen
    alertLengthMS = 5000;
    alertStartMS = millis();
    alertScreen = true;
    alertSound = true;
    ledcWriteTone(pinAudio, audioFrequency);
    display.loadFont(Roboto_Regular_24);
    screenHelperAlert("No samples available", TFT_WHITE,TFT_BLACK,TFT_RED);
    display.unloadFont();
    debugMessage(String("samplePost() no samples to process this cycle"),1);
  }
  // Reset sample counters
  numSamples = 0;
  totalTemperatureF.clear();
  totalHumidity.clear();
  totalCO2.clear();
  totalVOCIndex.clear();
  totalPM25.clear();
  debugMessage(String("samplePost() end"), 1);
}
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

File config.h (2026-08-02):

/*
  Project:      Powered Air Quality
  Description:  public (non-secret) configuration data
*/

#pragma once

// Configuration Step 1: Create and/or configure secrets.h. Use secrets_template.h as guide to create secrets.h

// Configuration Step 2: Set network data endpoints
// #define MQTT     // log sensor data to MQTT broker
// #define HASSIO_MQTT  // And, if MQTT enabled, with Home Assistant too?
#define INFLUX // Log data to InfluxDB server
#define THINGSPEAK  // Log data to ThingSpeak

// Configuration Step 3: Set debug message output
// comment out to turn off; 1 = summary, 2 = verbose
#define DEBUG 2

// Configuration Step 4: Simulate WiFi and sensor hardware, returning random but plausible values.
// Comment out to turn off
// #define HARDWARE_SIMULATE

// Configuration variables that are less likely to require changes

// Open Weather Map (OWM)
const String kOWMServer = "https://api.openweathermap.org/data/2.5/";
const String kOWMAQMPath = "air_pollution?";
const String kOWMForecastPath = "forecast?";
// OWM Air Pollution scale from https://openweathermap.org/api/air-pollution
const String OWMPollutionLabel[5] = {"Good", "Fair", "Moderate", "Poor", "Very Poor"};

// UI
enum screenNames {sMain, sCO2, sPM25, sVOC, sForecast};

// screen layout assists in pixels
constexpr uint8_t kXMargins = 5;
constexpr uint8_t kYMargins = 5;
constexpr uint8_t kYStatusRegion = 30; // display.height()/8 assuming 320x240 screen

// How many samples are retained in a FIFO queue
constexpr uint8_t kSampleCapacity = 10;

// warnings
const String warningLabel[4]={"Good", "Fair", "Poor", "Bad"};
// Subjective color scheme using 16 bit ('565') RGB colors
constexpr uint16_t warningColor[4] = {
    0x07E0, // Green = "Good"
    0xFFE0, // Yellow = "Fair"
    0xFD20, // Orange = "Poor"
    0xF800  // Red = "Bad"
  };

constexpr uint8_t screenBLMax = 255;
constexpr uint8_t screenBLLow  = 52;   // 255 * 0.20

// The  background color used for the "TODAY" column in the Weather Forecast screen (see screens.cpp)
#define TFT_TODAYBG 0x41e8

// timers
// Internet and network endpoints
constexpr uint8_t timeConnectTimeoutSeconds = 10; // how long WFM attempts network connect before failing
constexpr uint32_t timeOWMRenewMS = 1800000; // min time between OWM calls
constexpr uint32_t timeWebPortalTimeOutMS = 180000; // how long web configuration portal stays active

constexpr uint32_t timeHardwareSleepTimeμS = 10000000;  // sleep time if hardware error occurs
// button
constexpr uint32_t timeStartPortalHoldMS = 5000;  // long-press duration to start config portal
constexpr uint32_t timeDeviceResetHoldMS = 10000; // Long-press duration to wipe config

constexpr uint32_t timeScreenSaverStartMS = 300000; // switch to screen saver if no input after this period

// sampling and reporting intervals
#if defined (DEBUG) && !defined (HARDWARE_SIMULATE)
  // time between sensor reads, e.g. samples
  constexpr uint32_t timeSensorSampleMS = 30000; // minimum inter-sample time for many sensors
  // time between samplePost()
  constexpr uint32_t timeReportMS = 90000;
#elif defined(DEBUG) && defined (HARDWARE_SIMULATE) // rapid samples for debugging
  constexpr uint32_t timeSensorSampleMS = 10000;
  constexpr uint32_t timeReportMS = 100000; // 10 samples per report
#else // Production sample pace
  constexpr uint32_t timeSensorSampleMS = 60000;
  constexpr uint32_t timeReportMS = 900000;
#endif

constexpr uint8_t reportFailureThreshold = 3; // report attempt failures before UI alert starts

// hardware
constexpr uint8_t screenRotation = 3; // CYD 2.8; horizontal orientation with USB port on left side

// sensors
constexpr uint8_t kRequiredRisingDeltas = 3; // minimum samples required to trigger rapid rise alert

// simulation boundary values
constexpr uint8_t OWMAQIMin = 1;  // https://openweathermap.org/api/air-pollution
constexpr uint8_t OWMAQIMax = 5;

constexpr uint16_t OWMPM25Min = 0;
constexpr uint16_t OWMPM25Max = 100; 

constexpr uint8_t networkRSSIMin = 30; // ESP32 abs(WiFi.RSSI()) spec
constexpr uint8_t networkRSSIMax = 100;

// tempF value threshholds
constexpr uint16_t sensorTempFMin =       14; // -10C per SCD40, SEN66 datasheet
constexpr uint8_t sensorTempFComfortMin = 65;
constexpr uint8_t sensorTempFComfortMax = 80;
#ifdef SCD40
  constexpr uint16_t sensorTempFMax =       140; // 60C per SCD4X datasheet
#else
  constexpr uint16_t sensorTempFMax =       122;
#endif

// humidity value thresholds
constexpr uint16_t sensorHumidityMin =    0; // RH% per datasheet
constexpr uint8_t sensorHumidityComfortMin = 40;
constexpr uint8_t sensorHumidityComfortMax = 60;
constexpr uint16_t sensorHumidityMax =    100;
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

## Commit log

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2023-02-14 MQTT changes, internetAvailable fixes
    changed MQTT config parameters for topics to be more descriptive and match RCO2 parameters. Put all MQTT and influxDB publish attempts behind a internetAvailable check.
    [config.h]
2023-02-16 Internet services fixes
    Significant changes to standardize and fix debug messaging and logic handling for routines that connect to the Internet. Also fixed a influxDB bug.
    [config.h]
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2024-10-14 screen sorta works
    code now compiles without network endpoints enabled. Screen displays pm25 data for wrong screen dimensions.
    [config.h]
2024-10-21 cleanup
    bug fixes and UI element movement
    [powered_air_quality.ino]
2024-10-24 continued cleanup
    UI placement improvements, bug fixes, moved from US to European AQI value display. Compile without HARDWARE_SIMULATE should be ready minus ESP32 specific routines (waiting for core hardware change)
    [config.h, powered_air_quality.ino]
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2024-11-10 network endpoints working
    changes required for MQTT and InfluxDB network endpoint reporting. DWEET, HASSIO_MQTT, and ThingSpeak are untested and may not work.
    [config.h, powered_air_quality.ino]
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2024-11-17 minor fixes
    fixes based on testing hardware_simulate
    [config.h, powered_air_quality.ino]
2024-11-17 issue resolution
    resolving github issue 5
    [config.h]
2024-11-24 bug fixes/readability
    readability changes plus small bug fixes related to debug logging. Two changes to functionality was the addition of a initializing message at bootup (from other AQ projects), and changing the default screen to screenSaver() to protect the TFT.
    [config.h, powered_air_quality.ino]
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2025-06-25 SCD4x changes
    Support for 1.0 library, sensor read error handling improvement.
    [config.h, powered_air_quality.ino]
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2025-06-30 MQTT compile fix
    extending a variable name change into conditional MQTT code
    [config.h, powered_air_quality.ino]
2025-06-30 screenVOC() + mqtt compile fix
    UI improvement to screenVOC() and changes needed for MQTT to compile with ESP 3.x
    [config.h, powered_air_quality.ino]
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2025-07-05 cyd backplane
    Adding build files for cyd backplane. Sensors attach to the backplane which is attached to the backside of the cyd legs
    [CYD Stand Leg Landscape.3mf]
2025-08-09 Refactor config and improve WiFi reconnect logic
    Added and reorganized display and network configuration variables for clarity. Improved WiFi reconnection logic in powered_air_quality.ino to periodically attempt reconnects and use a connection timeout. Fixed variable naming for temperature in sensorRead().
    [config.h, powered_air_quality.ino]
2025-08-09 Refactor timing variables to use milliseconds
    Replaces sensor and report interval variables with millisecond-based equivalents for improved timing precision. Updates all related variable names and logic in both config.h and powered_air_quality.ino to consistently use millisecond units.
    [config.h, powered_air_quality.ino]
2025-08-09 Add DEVICE_ID to InfluxDB tags and MQTT topics
    DEVICE_ID is now included as a tag in InfluxDB data and as part of the MQTT topic structure, improving device identification in both data storage and messaging. Also fixed minor formatting in fmap function.
    [powered_air_quality.ino]
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2025-08-28 Refactor MQTT functions and update WiFi include
    Refactored MQTT connection and publishing functions for improved clarity and reliability, including changes to argument types and error handling. Unified WiFi include to <WiFi.h> for both ESP8266 and ESP32, and updated function signatures to use uint32_t for RSSI. Removed redundant WiFi.mode(WIFI_STA) call.
    [powered_air_quality.ino]
2025-08-28 fixed status bug in sensorCO2Read()
    Fixed return bug in sensorCO2Read() when HARDWARE_SIMULATE enabled. Refactored sensor and WiFi initialization in powered_air_quality.ino to always include relevant code, regardless of simulation mode.
    [config.h, powered_air_quality.ino]
2025-09-02 WiFiManager, ESP32 Prefs, and PubSubClient
    Replaces preprocessor macros with const Strings for OpenWeatherMap and hardware config, introduces powered_air_quality.h for shared data structures, and refactors MQTT to use PubSubClient instead of Adafruit_MQTT. Adds persistent configuration storage using Preferences and WiFiManager for runtime configuration, including MQTT and endpoint parameters. Cleans up and modularizes code, improves WiFi/network handling, and updates secrets_template.h to match new config approach.
    [config.h, powered_air_quality.ino]
2025-09-03 Enable debug output and improve WiFiManager setup
    Updated WiFiManager to use the device type in the AP name and improved user feedback with a configuration alert. Cleaned up button pin configuration comments and clarified debug messages for WiFi connection failures.
    [config.h, powered_air_quality.ino]
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2025-09-03 Remove unused networkWiFiMessage function
    Deleted the networkWiFiMessage function, which converted WiFi status codes to strings, as it is no longer used in the codebase.
    [powered_air_quality.ino]
2025-09-04 Enable MQTT support and add keep-alive handling
    MQTT logging is now enabled by default in config.h. Added a keep-alive interval for MQTT and logic in the main loop to periodically ping the broker or reconnect if disconnected. Improved debug messages and error handling in MQTT connection and publish routines.
    [config.h, powered_air_quality.ino]
2025-09-04 Refactor InfluxDB config and tagging, update data flow
    Replaces hardcoded InfluxDB parameters with a structured influxdbConfig object, updates tag keys and value keys for InfluxDB, and modifies the post_influx function signature and usage to include NOX readings and use new config. Also updates WiFiManager and NV config handling for InfluxDB, and improves debug output for MQTT and InfluxDB writes.
    [config.h, powered_air_quality.ino]
2025-09-04 Refactor debug and InfluxDB connection logic
    Changed debugMessage to use uint8_t for messageLevel across files. Updated InfluxDB connection logic to use a timeout-based approach instead of fixed retry attempts. Refactored RSSI handling to use hardwareData.rssi and improved configuration and secrets templates for clarity and consistency.
    [config.h, powered_air_quality.ino]
2025-09-07 fix typos, and adjust MQTT reporting
    alert text changes and ensure endpoint reporting is disabled when HARDWARE_SIMULATE is defined. Also update secrets_template.h with an additional InfluxDB key example.
    [config.h, powered_air_quality.ino]
2025-09-07 Fix NOx data assignment and update device ID template
    Corrects the assignment of NOx data to use the environment data object instead of the device data object in post_influx.cpp. Updates the defaultDeviceID template in secrets_template.h to use only the upper 32 bits of the MAC address for improved uniqueness.
2025-09-10 Enable debug, InfluxDB, and SEN54SCD40 sensor; fix timing bugs
    Fixed timing comparison in WiFi reconnect logic by casting to long, and ensured timeLastReportMS is updated after reporting in loop(). Also corrected debug message formatting.
    [config.h, powered_air_quality.ino]
2025-09-10 Improve sensor config loading and error logging
    Moved loadNVConfig() before sensorInit() in setup() to ensure altitude data is available for sensor initialization. Added debug messages for altitude, latitude, and longitude loading. Enhanced error logging in sensorRead() for SCD40 read failures and out-of-range CO2 readings. Commented out redundant debug message for sensor read failure in loop().
    [powered_air_quality.ino]
2025-09-11 Refactor hardware error sleep handling and timing
    Replaces hardwareRebootInterval (seconds) with hardwareErrorSleepTimeμS (microseconds) for more precise deep sleep timing on hardware errors. Updates related function signatures and usages to use microseconds, and improves sensor initialization error handling and messaging.
    [config.h, powered_air_quality.ino]
2025-09-24 Refactor endpoint reporting to processSamples function
    Renamed endPointWrite to processSamples and updated logic to separate sample processing from network reporting. Improved debug messages and ensured sample counters are reset regardless of network status.
    [powered_air_quality.ino]
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2025-09-25 Fixed typo in getDeviceId
    [powered_air_quality.ino]
2025-11-04 two layer ui system
    Changed from screen rotation based on touch input to two UI layers (main, component) with screen saver overlay. Replaced screen index constants with an enum for screen names and updated screen navigation logic to use the new enum. Simplified touch input handling and screen transitions, consolidated main screen rendering, and removed unused variables. Also fixed font include order and improved comments for sensor initialization delays.
    [config.h, powered_air_quality.ino]
2025-11-05 Refactor CO2 data handling for graphing
    Replaces the GRAPH_POINTS macro with a graphPoints constant and stores CO2 samples in an array within the sensorData struct for improved graphing and data retention. Updates all relevant logic to use the new array, refactors simulation and sensor reading routines to retain CO2 samples, and improves code clarity and consistency in header includes and comments.
    [config.h, powered_air_quality.ino]
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2025-11-12 Refactor graph drawing functions for CO2 display
    Renamed and consolidated the CO2 graph drawing logic into screenHelperGraph, removing the redundant screenGraph and screenCO2Graph functions. Updated all references to use the new helper function and improved comments for clarity. Also replaced fillRect with fillRoundRect in screenCO2 for improved UI appearance.
    [powered_air_quality.ino]
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2025-11-13 Refactor VOC index to use array for historical data
    Changed sensorData.vocIndex from a float to a float array to store historical VOC index values, similar to CO2. Updated all references and display logic to use the latest value in the array. Added retainVOC() function to manage the VOC index array as a FIFO buffer. Improved debug messages and fixed minor comments and variable naming for clarity.
    [powered_air_quality.ino]
2025-11-17 Refactor sensor thresholds and graphing for CO2, PM, VOC
    Consolidated and renamed sensor threshold constants for CO2, PM, and VOC in config.h for clarity and consistency. Updated data types for CO2 arrays to float and adjusted related functions and graphing logic to use the new threshold names and types. Improved VOC and CO2 screen rendering and graphing to use parameterized data arrays and color logic, and fixed simulated sensor value scaling.
    [config.h, powered_air_quality.ino]
2025-11-21 Disable debug output and fix NOx label position
    Adjusted the vertical position of the NOx label in screenMain() to display at three-quarters height instead of one-quarter.
    [config.h, powered_air_quality.ino]
2025-11-30 Refactor device ID and sleep functions, add comfort thresholds
    Renamed getDeviceId to deviceGetID and powerDisable to deviceDeepSleep for clarity. Added configurable comfort thresholds for temperature and humidity in config.h and updated display logic to use these values. Improved color coding for out-of-range values and fixed min/max assignment for sVOC in screenHelperGraph. Moved debugMessage function to the end for better organization.
    [config.h, powered_air_quality.ino]
2025-12-02 Switch to TFT_eSPI display library and update config
    Replaced Adafruit_ILI9341 with TFT_eSPI for display handling and updated all related drawing/color constants and font methods accordingly. Changed sensor configuration in config.h to enable SENSOR_SEN66 and DEBUG output. Refactored code to use TFT_eSPI's API, including color constants, font handling, and text measurement functions.
    [config.h, powered_air_quality.ino]
2025-12-02 Improve debug messages and screen alert font handling
    Updated debug messages for clarity in sensor initialization and error handling. Enhanced screenAlert function to clarify font size logic, switching from 'small' to 'medium' font terminology and improving debug output. Removed unused SEN6x serial number retrieval for cleaner sensor initialization.
    [config.h, powered_air_quality.ino]
2025-12-02 Remove unused TFT SPI pin definitions
    Deleted the TFT_MISO, TFT_MOSI, and TFT_SCLK pin definitions from config.h as they are no longer needed.
    [config.h]
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2025-12-06 Refactor screen display functions and remove weather icon mapping
    Replaces screenCurrentInfo() with screenTempHumidity(), focusing on temperature and humidity display and removing particulate matter, CO2, and weather icon rendering. Comments out screenAggregateData() and OWMtoMeteoconIcon(), removing aggregate sensor data and weather icon mapping logic. Adds debug output for JsonDocument memory usage in OWM data read functions.
    [powered_air_quality.ino]
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2025-12-23 Refactor OWM API handling and optimize JSON parsing
    Replaces String-based HTTP/JSON handling for OpenWeatherMap (OWM) weather and air quality data with direct HTTPClient usage and filtered streaming JSON parsing to reduce memory usage. Updates data structures for more efficient types (e.g., char arrays, uint8_t), removes the networkHTTPGETRequest helper, and rewrites OWMtoMeteoconIcon for improved icon mapping. These changes improve performance, reliability, and code clarity.
    [powered_air_quality.ino]
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2025-12-26 UI bug fixes and improvements
    Extracted repeated status region drawing code into a new helper function, screenHelperIndoorOutdoorStatusRegion, to reduce duplication in screenTempHumidity and screenPM25. Improved WiFi signal indicator to show red bars when no signal is detected. Fixed logic for outdoor temperature and humidity comfort checks, and made minor adjustments to label placement and legend positioning.
    [powered_air_quality.ino]
2025-12-29 UI updates, ThingSpeak debug message
    Refactored post_thingspeak.cpp to use uint16_t for HTTP code and improved debug messages for success/failure. Updated powered_air_quality.ino to use drawString for text rendering, improved layout and font handling for alerts and status regions, and enhanced weather icon display logic.
    [config.h, powered_air_quality.ino]
2025-12-30 WiFiManager OTA support
    Renamed button constants for clarity and split long-press actions into separate durations for starting the config portal and device reset. Refactored button handling logic into checkButtonPress(), supporting both portal and reset actions. Integrated WiFiManager as a persistent object, improved WiFi connection logic, and enhanced user feedback for configuration steps. Updated .gitignore to exclude build/ directory.
    [config.h, powered_air_quality.ino]
2026-01-18 Add User_Setup_Select.h and improve alert display
    Added User_Setup_Select.h for TFT display configuration selection. Replaced screenAlert with screenHelperAlert for improved, flexible alert message rendering using rounded rectangles and better text fitting. Updated config.h to enable hardware simulation and disable ThingSpeak logging. Refactored code to use new alert helper and improved handling of OWM data and string copying.
    [User_Setup_Select.h, config.h, powered_air_quality.ino]
2026-01-18 Refactor sample processing and improve documentation
    Disabled hardware simulation in config.h. Updated processSamples to take numSamples by reference and reset it after processing, moving the reset logic inside the function. Improved error handling in OWMAirPollutionRead by checking deserialization errors. Added doxygen blocks for OWMtoMeteoconIcon and processSamples functions. Minor cleanup of unused variables and comments.
    [config.h, powered_air_quality.ino]
2026-04-06 Enable SEN66 sensor and add NOx screen
    Switch active sensor to SEN66 in config.h to enable NOx readings. Add extern declaration for screenNOX in powered_air_quality.ino. Fix variable name in screens.cpp (totalNOxIndex) and update the NOx display call to use the correct identifier so the NOx UI renders and compiles correctly.
    [config.h, powered_air_quality.ino]
2026-04-06 Enable DEBUG/INFLUX; rename VOC to NOx vars
    Uncomment DEBUG and INFLUX macros in config.h to enable verbose debug output and InfluxDB logging. In screens.cpp, rename VOC-related variables to NOx (xVOCCircle/yVOCCircle/xVOCLabel/yVOCLabel -> xNOxCircle/yNOxCircle/xNOxLabel/yNOxLabel) and update their uses in screenNOX() to correct labeling and drawing. These changes fix incorrect variable names for the NOx display and enable debugging and Influx logging.
    [config.h]
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2026-04-28 Replace main with alerts branch which includes new_screens content
    [SEN6x_Example_Retainer.STEP, complete_2_20_2026.3mf]
2026-04-28 Climatron compile fixes
    Remove an unused extern for screenAlert, add extern prototypes for co2Range, pm25Range, vocRange, and noxRange (implemented in screens.cpp), and move the 100ms animation delay into the CLIMATRON block to avoid a duplicate delay call in loop(). These changes tidy up declarations and ensure the 10Hz animation timing is only applied when CLIMATRON is enabled.
    [powered_air_quality.ino]
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2026-05-01 Rename graphPoints to kSampleCapacity
    Replace the ambiguous graphPoints constant with kSampleCapacity in config.h and update all usages across the codebase.
    [config.h, powered_air_quality.ino]
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2026-05-06 build and debug improvements
    Add bin/ to .gitignore. Remove build-cache usage from Windows build scripts. ThingSpeak integration now uses a shared extern WiFiClient and an angled include (<ThingSpeak.h>) in post_thingspeak.cpp. Update powered_air_quality.ino to improve logging and error reporting (replace Serial.println with debugMessage, reword debug strings) and add a safety debug when sampleEvaluate() returns false. Miscellaneous cleanup of comments and minor log formatting.
    [User_Setup_Select.h, config.h, powered_air_quality.ino]
2026-05-13 Add rapid CO2 detection; update build scripts
    Rename and simplify Windows build scripts (build_esp32*.ps1 => build*.ps1), set SKETCH to project root ("."), add PORT, tweak verbose/tips, and add build_discovery_upload.ps1 to compile+upload. Enable HARDWARE_SIMULATE in config.h and introduce timing/config constants (kRequiredRisingDeltas, kSigmaMultiplier, kMinSigmaFloor) with adjusted sample/report intervals for simulated/debug modes. Overhaul sampleEvaluate() in powered_air_quality.ino: use a fixed recent-delta window, compute mean/std, detect rapid sustained rising trend (with trendAlreadyReported), add debug logging, and trigger audible/visual alert actions in loop when detected. Add a new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
    [config.h, powered_air_quality.ino]
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2026-05-16 Refactor Influx writes & header bar rendering
    Improve InfluxDB write handling and refactor screen header rendering.
    - post_influx.cpp: Reverse writePoint checks to treat true as success, set success flag accordingly, and provide clearer debug output (separate success/error messages, include line-protocol on success and error message on failure). Flush buffer unchanged.
    - screens.cpp: Rename and change screenHelperComponentSetup to screenHelperHeaderBar(measure, datatype, header); update all callers to pass appropriate Measure and datatype. Header bar now chooses background color via getWarningColor(datatype, currentValue). Adjust text and WiFi/report icon colors to improve contrast and add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
2026-05-16 Reenable CO2 warning labels, CO2 screen work, log improvements
    Rename warning label array and add getWarningLabel helper; display the textual warning on the CO2 screen, adjust font/positioning and append unit, and hide the color legend. Update various debug messages and severity levels (clarify samplePost text, add OWMAirPollutionRead start/end logs, change sensor error texts) and increase verbosity level for several sensor error/out-of-range messages to reduce noise. Misc UI/logic tweaks to improve labeling and diagnostics.
    [config.h, powered_air_quality.ino]
2026-05-16 fix merge issue
    getWarningColor() moved to powered_air_quality.ino
2026-05-16 Merge fix
    getWarningColor() is in powered_air_quality.ino
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2026-05-25 More work on display screens
    Refactor multiple screen rendering routines in screens.cpp: rework VOC and NOx displays to use arcMeter with centered circle layout and updated font/labels, show a "No data" message when VOC has no samples, adjust CO2 graph height calculation, and simplify/clarify graph drawing logic. Improve screenHelperReportStatus logic and add debug messages, and consolidate screenHelperGraph text/font handling, axis positioning, drawString usage, and debug output wording for clearer diagnostics.
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2026-06-16 Use Roboto fonts and handle missing NOx
    Replace various FreeSans fonts with Roboto font loads/unloads across UI screens, adjust some label positions, and add defensive handling for missing NOx data.
    [powered_air_quality.ino]
2026-06-17 Post and WiFi status icons to graphics primitives
    switching the Post and WiFi status icons to graphics primitives aligned with Figma design. Removing PNG functionality. Post icon is borked, will fix.
    [config.h]
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2026-06-20 Use Roboto font and refine alert UI helper
    Replace ad-hoc FreeSans usage with display.loadFont()/unloadFont() around alert draws. Rename screenHelperAlert parameters to fgColor/bgColor and ensure text background is applied (setTextColor with bg and fillRoundRect using bgColor).
    [powered_air_quality.ino]
2026-06-28 FastLED init fix
    FastLED seemingly does not use NEOPIXEL descriptor anymore. Backing this change out.
    [config.h, powered_air_quality.ino]
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2026-07-08 in-flight fixes
    nvconfigRead now checks to see if there are existing paramters to read. If not, it fails and triggers a load and write of the default parameters to nv storage before networkOpenWiFiManager runs. The web portal now displays current configuration parameter data rather than always showing defaults.
    renamed default values in secrets.h to kXXXX format.
    Moved sensor initialization delays from setup() to sensorInit()
    Added setSensorAltitude() to SEN66 code path
    [powered_air_quality.ino]
2026-07-08 bug fixes and endpoint global data structures
    Fixed bugs. Exposing mqtt and influx endpoint config as global so nvconfig parameters can be written for all endpoints even if they are not used. If user gets new binary that changes endpoint targets, the nvprefs (at least default) will already be stored
    [config.h, powered_air_quality.ino]
2026-07-10 in progress
    web portal UI bugs fixed, and callbacks now better attempt to save config parameters if the user doesn't enter their WiFi credentials properly.
    Issues - there appear to be issues re-instantiating the web portal, and the influx environment parameters are not being handled properly, causing influx writes not to work.
    cleaned up some chassis file naming
    [case 022026.3mf, case 042626.3mf, complete_4_26_2026_rev.3mf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]
2026-07-15 WiFiMgr and Thingspeak changes
    Changes needed for WiFiMgr to work properly for both the initial device configuration and non blocking web portal. Changes to multiple network endpoint connection code for error handling and more robust connection handling (tested with Starlink).
    [config.h, powered_air_quality.ino]
2026-07-16 fixes to compile
    fixes for successful compilation. Remember, compile does not equal work
    [config.h, powered_air_quality.ino]
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2026-07-20 secrets template fix
    Aligning variable names in secrets template and code
    [config.h]
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2026-07-28 remove all nox references
    code no longer stores NAN NOx values or writes NAN values to network endpoints
    [config.h, powered_air_quality.ino]
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
